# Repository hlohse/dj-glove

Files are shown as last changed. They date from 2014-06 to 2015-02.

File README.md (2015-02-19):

### Compilation

#### Windows

Make sure the following software is installed:

    Visual Studio Express 2013
    Arduino IDE

To make use of virtual MIDI ports, use the following 3rd party software:

    Go to http://www.tobias-erichsen.de/
    Download and install loopMIDI
    Download the virtualMIDI SDK
    Copy the following virtualMIDI SDK C files to the ThirdParty directory:
        teVirtualMidi.h
        teVirtualMidi32.lib

#### Linux (Ubuntu 14.04)

Make sure the following packages are installed:

    g++ (>= 4.8)
    arduino
    libasound2-dev
    libbluetooth-dev

#### All Platforms

Pair your PC with the Arduino's Bluetooth module using the PIN 1234.

Adjust default Bluetooth address to your module's in PC/BluetoothDevice.cpp, BluetoothDevice::Arduino.

### About

Advanced project of Robotics Lab ST14, University of Heidelberg, Germany.

Authors: Jan-Lukas Tirpitz, Henning Lohse

Supervisors: Karsten Krispin, Thomas Kloepfer

[Demo Video](https://www.youtube.com/watch?v=biKKQlQEOuE)

[Project website (German)](http://joanna.iwr.uni-heidelberg.de/projects/2014SS_DJHANDSCHUH/hardware.html)

[Robotics Lab website](http://joanna.iwr.uni-heidelberg.de/rlab/en/about)

### Copyright

Copyright (c) 2014 Jan-Lukas Tirpitz, Henning Lohse

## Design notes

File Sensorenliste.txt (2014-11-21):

MOUSER:

Flex-Sensor: 5,60€
http://de.mouser.com/ProductDetail/Spectra-Symbol/FS-L-0055-253-ST/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

oder doch der lange?:

3x Beschleunigungssensor (3-Axis): 1,34€
http://de.mouser.com/ProductDetail/Freescale-Semiconductor/MMA8451QR1/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

Entfernungsmesser(1 - 200mm): 2,42€
http://de.mouser.com/ProductDetail/Vishay-Semiconductors/VCNL3020-GS08/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

6x empfindliche Minidruckknöpfe (zwischen die Finger): 0,80€
http://de.mouser.com/ProductDetail/Panasonic/EVP-AWBA2A/?qs=sGAEpiMZZMsgGjVA3toVBGTSKfeK9LPKxL05x3Q68mA%3d

4x Potentiometer 0,60€:
http://de.mouser.com/ProductDetail/Bourns/PTV09A-4015F-B503/?qs=sGAEpiMZZMtC25l1F4XBU4LIzrlRxKBZi5l7wwo1KCE%3d

7-segment-anzeige 8 (2 digits):
http://de.mouser.com/ProductDetail/Kingbright/ACDA02-41SGWA-F01/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

7-segment-treiber + SR:
http://de.mouser.com/ProductDetail/STMicroelectronics/STP16CP05MTR/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

4x Drehknöpfe: 0,634€
http://de.mouser.com/ProductDetail/Eagle-Plastic-Devices/450-4760/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
eventuell auch andre mit eingebauter Druckknopffunktion oder Stufendrehschalter für Pgrogramm-/Kanal-Wahl

10x Druckknöpfe:
http://de.mouser.com/ProductDetail/Schurter/13019314/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

2x Spannungsregler:
http://de.mouser.com/ProductDetail/Texas-Instruments/UA78M33CDCYR/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

Schmitt-Trigger:
http://de.mouser.com/ProductDetail/STMicroelectronics/M74HC14YRM13TR/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

Kondensator: Elektrolyt 22uF
http://de.mouser.com/ProductDetail/Nichicon/UWX0J220MCL2GB/?qs=sGAEpiMZZMtZ1n0r9vR22RxmuzErLMSV6cxZgqZwSVw%3d

Kondensator: Elektrolyt 10uF
http://www.mouser.de/ProductDetail/Cornell-Dubilier/AVE106M16A12T-F/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

FARNELL:

Gyroskop: 8,88€
http://de.farnell.com/stmicroelectronics/l3g4200d/gyro-mems-3achsen-16llga-16lga/dp/1872924

1,0V-Spannungswandler: 1,10€
http://de.farnell.com/stmicroelectronics/ld39015m10r/v-reg-1-5-5-5v-0-15a-1v-5sot23/dp/2311330

KeKo 10nF: 
http://de.farnell.com/avx/08051c103jat2a/keramikkondensator-0-01uf-100v/dp/2332713

Keko 470nF:
http://de.farnell.com/jsp/search/productdetail.jsp?sku=1867963

CONRAD:
2x SChiebeschalter (on/off - bypass)
LiPo (3,7V, 2000mAh mindestens): 10,81€

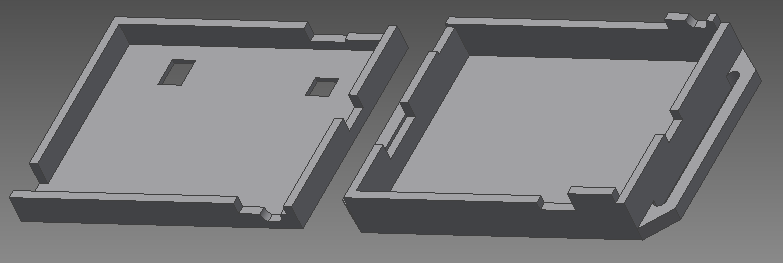
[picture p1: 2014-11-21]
Akkubox/Akkubox.png

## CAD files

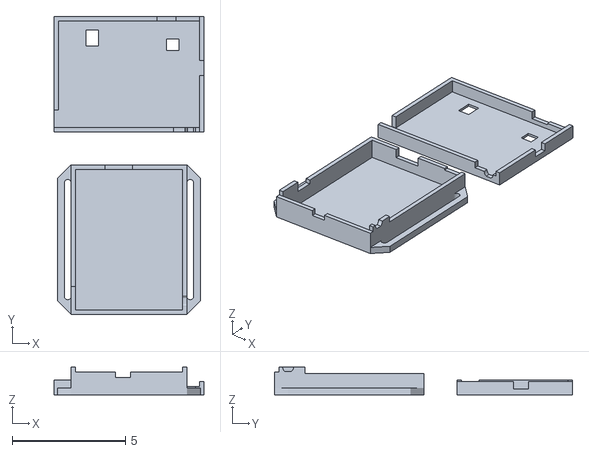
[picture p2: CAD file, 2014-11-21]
Akkubox/Akkubox.stl
6.60 x 13.1 x 1.23

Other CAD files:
Akkubox/Akkubox.ipt
Akkubox/OldVersions/Akkubox.0004.ipt

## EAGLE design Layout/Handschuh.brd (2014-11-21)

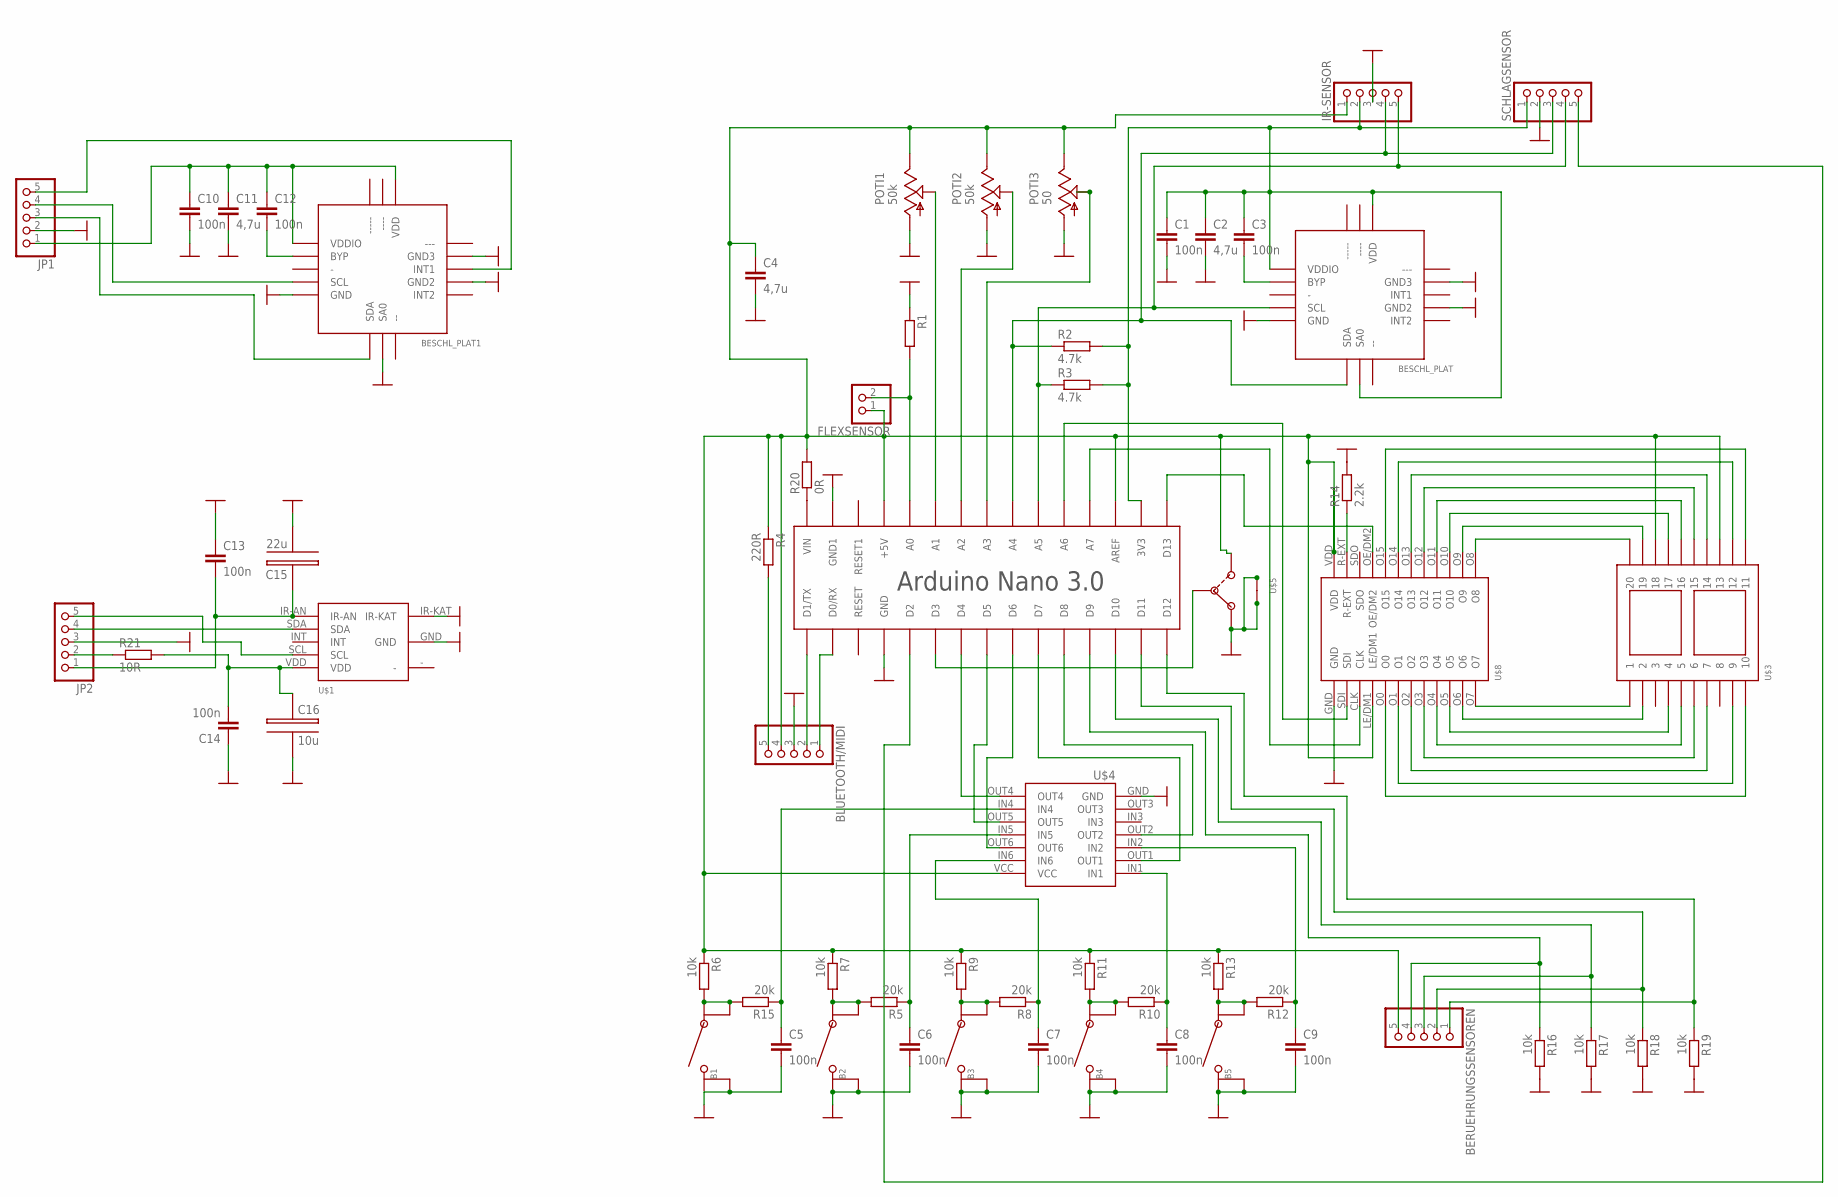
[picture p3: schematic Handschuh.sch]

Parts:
B1, B2, B3, B4, B5: BUTTON
BERUEHRUNGSSENSOREN: PINHD-1X5/90; 1X05/90
BESCHL_PLAT, BESCHL_PLAT1: BESCHLEUNIGSUNGSSENSOR; BESCHLEUNIGUNGSSENSOR
BLUETOOTH/MIDI: PINHD-1X5/90; 1X05/90
C1, C3, C5, C6, C7, C8, C9, C10, C12, C13, C14: 100n; C0805
C2, C4, C11: 4,7u; C0805
C15: 22u; 22U-KONDENSATOR
C16: 10u; 22U-KONDENSATOR
FLEXSENSOR: PINHD-1X2/90; 1X02/90
IR-SENSOR: PINHD-1X5/90; 1X05/90
JP1, JP2: PINHD-1X5/90; 1X05/90
POTI1, POTI2: 50k; POTI
POTI3: 50; POTI
R1: R-EU_M0805; M0805
R2, R3: 4.7k; M0805
R4: 220R; M0805
R5, R8, R10, R12, R15: 20k; M0805
R6, R7, R9, R11, R13, R16, R17, R18, R19: 10k; M0805
R14: 2.2k; M0805
R20: 0R; M0805
R21: 10R; M0805
SCHLAGSENSOR: PINHD-1X5/90; 1X05/90
U$1: IR-SENSOR
U$2: ARDUINONANO; PDIP-32
U$3: 7-SEGMENT
U$4: SCHMITT-TRIGGER
U$5: SCHALTER
U$8: 7-SEGMENT-TREIBER

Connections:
3,3V: BESCHL_PLAT.SA0, BESCHL_PLAT.VDD, BESCHL_PLAT.VDDIO, C1.1, C2.1, C3.1, IR-SENSOR.2, R2.2, R3.2, SCHLAGSENSOR.1, U$2.3V3
3,3V1: BESCHL_PLAT1.VDD, BESCHL_PLAT1.VDDIO, C10.1, C11.1, C12.1, JP1.1
5V: BERUEHRUNGSSENSOREN.5, BLUETOOTH/MIDI.4, C4.1, FLEXSENSOR.1, IR-SENSOR.1, POTI1.VCC, POTI2.VCC, POTI3.VCC, R4.1, R6.1, R7.1, R9.1, R11.1, R13.1, R20.2, U$2.+5V, U$2.AREF, U$3.13, U$3.18, U$4.VCC, U$5.3, U$8.LE/DM1, U$8.VDD
GND: B1.2, B2.2, B3.2, B4.2, B5.2, BESCHL_PLAT.GND, BESCHL_PLAT.GND2, BESCHL_PLAT.GND3, BESCHL_PLAT1.GND, BESCHL_PLAT1.GND2, BESCHL_PLAT1.GND3, BESCHL_PLAT1.SA0, BLUETOOTH/MIDI.3, C1.2, C2.2, C4.2, C5.2, C6.2, C7.2, C8.2, C9.2, C10.2, C11.2, C13.1, C14.1, C15.-, C16.-, IR-SENSOR.3, JP1.2, JP2.3, POTI1.GND, POTI2.GND, POTI3.GND, R1.1, R14.2, R16.2, R17.2, R18.2, R19.2, SCHLAGSENSOR.2, U$1.GND, U$1.IR-KAT, U$2.GND, U$2.GND1, U$4.GND, U$5.1, U$5.4, U$5.5, U$8.GND
unnamed: R20.1, U$2.VIN
unnamed: BESCHL_PLAT1.BYP, C12.2
unnamed: B1.3, B1.4, R6.2, R15.2
unnamed: FLEXSENSOR.2, R1.2, U$2.A0
unnamed: BESCHL_PLAT.BYP, C3.2
unnamed: SCHLAGSENSOR.5, U$2.D2
unnamed: POTI1.VALUE, U$2.A1
unnamed: POTI2.VALUE, U$2.A2
unnamed: POTI3.VALUE, U$2.A3
unnamed: BESCHL_PLAT1.SCL, JP1.4
unnamed: BLUETOOTH/MIDI.2, U$2.D1/TX
unnamed: BLUETOOTH/MIDI.1, U$2.D0/RX
unnamed: BLUETOOTH/MIDI.5, R4.2
unnamed: BESCHL_PLAT1.SDA, JP1.3
unnamed: C6.1, R5.1, U$4.IN5
unnamed: B2.3, B2.4, R5.2, R7.2
unnamed: C7.1, R8.1, U$4.IN6
unnamed: B3.3, B3.4, R8.2, R9.2
unnamed: C8.1, R10.1, U$4.IN1
unnamed: B4.3, B4.4, R10.2, R11.2
unnamed: C9.1, R12.1, U$4.IN2
unnamed: B5.3, B5.4, R12.2, R13.2
unnamed: U$2.D4, U$4.OUT4
unnamed: U$2.D5, U$4.OUT5
unnamed: U$2.D6, U$4.OUT6
unnamed: U$2.D7, U$4.OUT1
unnamed: U$2.D8, U$4.OUT2
unnamed: U$2.A6, U$8.SDI
unnamed: C5.1, R15.1, U$4.IN4
unnamed: U$2.A7, U$8.CLK
unnamed: U$3.9, U$8.O1
unnamed: U$3.1, U$8.O7
unnamed: U$3.2, U$8.O6
unnamed: U$3.4, U$8.O5
unnamed: U$3.5, U$8.O4
unnamed: U$3.6, U$8.O3
unnamed: U$3.7, U$8.O2
unnamed: U$3.10, U$8.O0
unnamed: U$3.20, U$8.O8
unnamed: U$3.19, U$8.O9
unnamed: U$3.17, U$8.O10
unnamed: U$3.16, U$8.O11
unnamed: U$3.15, U$8.O12
unnamed: U$3.14, U$8.O13
unnamed: U$3.12, U$8.O14
unnamed: U$3.11, U$8.O15
unnamed: BERUEHRUNGSSENSOREN.4, R16.1, U$2.D9
unnamed: R14.1, U$8.R-EXT
unnamed: U$2.D13, U$8.OE/DM2
unnamed: BESCHL_PLAT1.INT1, JP1.5
unnamed: BERUEHRUNGSSENSOREN.3, R17.1, U$2.D10
unnamed: BERUEHRUNGSSENSOREN.2, R18.1, U$2.D11
unnamed: BERUEHRUNGSSENSOREN.1, R19.1, U$2.D12
unnamed: U$2.D3, U$5.2
unnamed: BESCHL_PLAT.SCL, IR-SENSOR.5, R3.1, SCHLAGSENSOR.4, U$2.A5
unnamed: C13.2, C15.+, JP2.1, U$1.IR-AN
unnamed: C14.2, C16.+, R21.2, U$1.VDD
unnamed: BESCHL_PLAT.SDA, IR-SENSOR.4, R2.1, SCHLAGSENSOR.3, U$2.A4
unnamed: JP2.2, R21.1
unnamed: JP2.4, U$1.SDA
unnamed: JP2.5, U$1.SCL

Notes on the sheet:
Arduino Nano 3.0

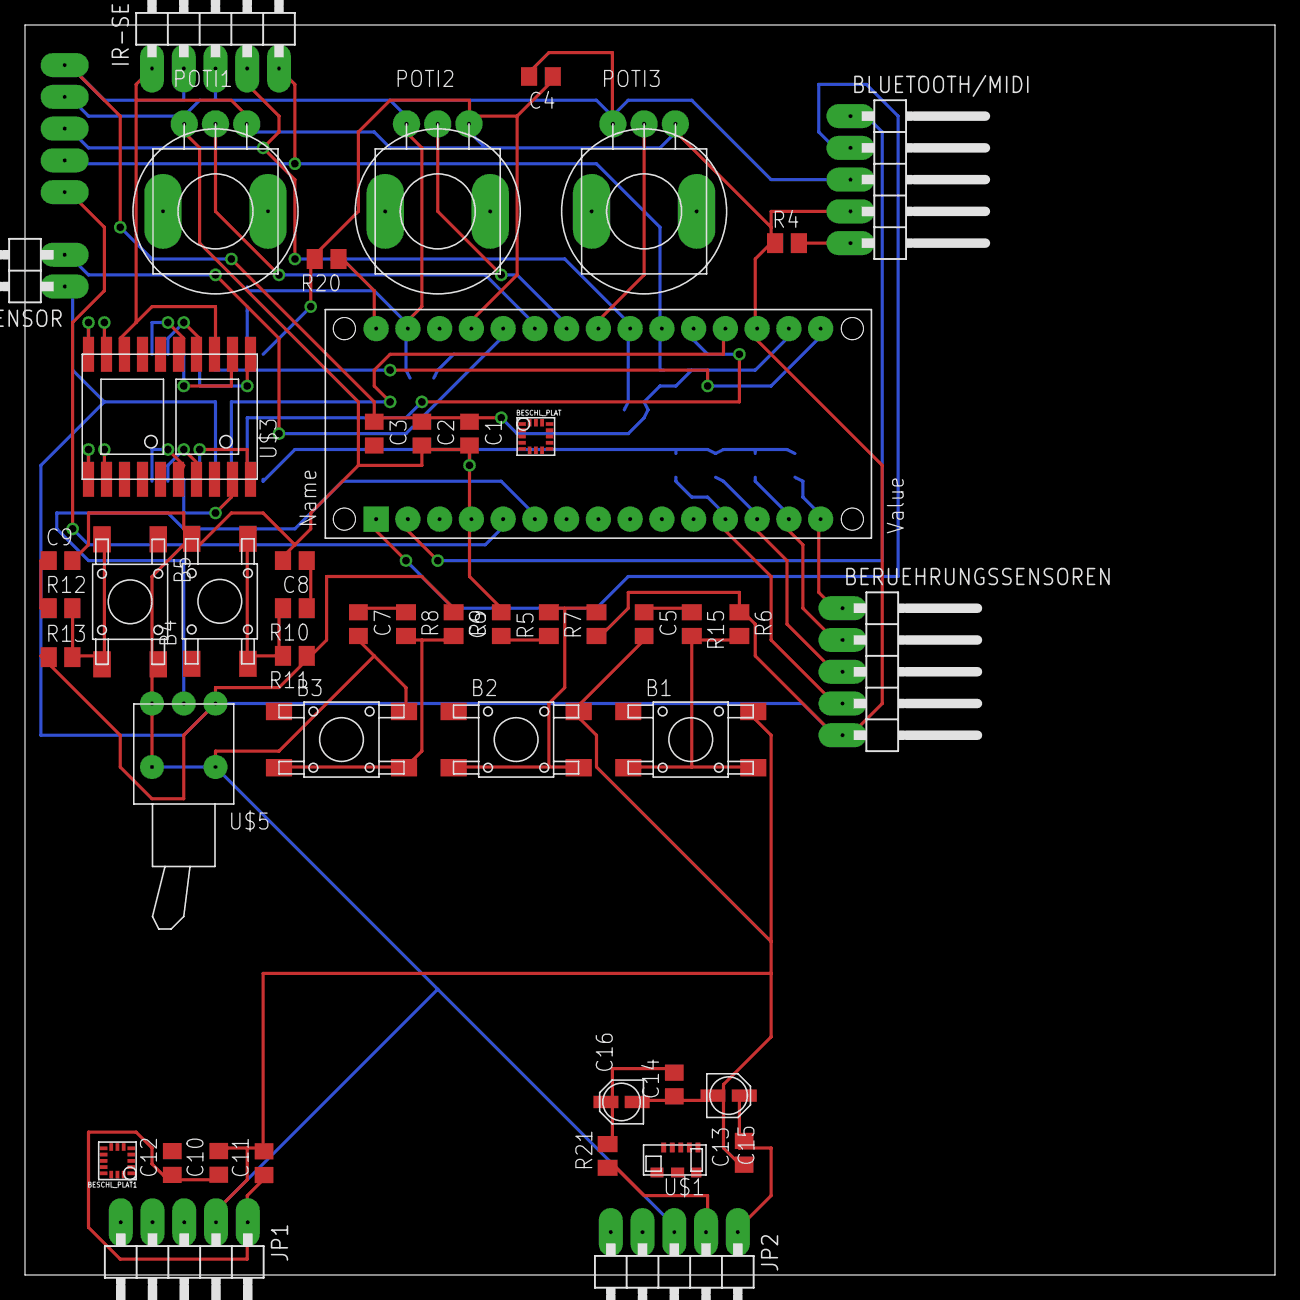
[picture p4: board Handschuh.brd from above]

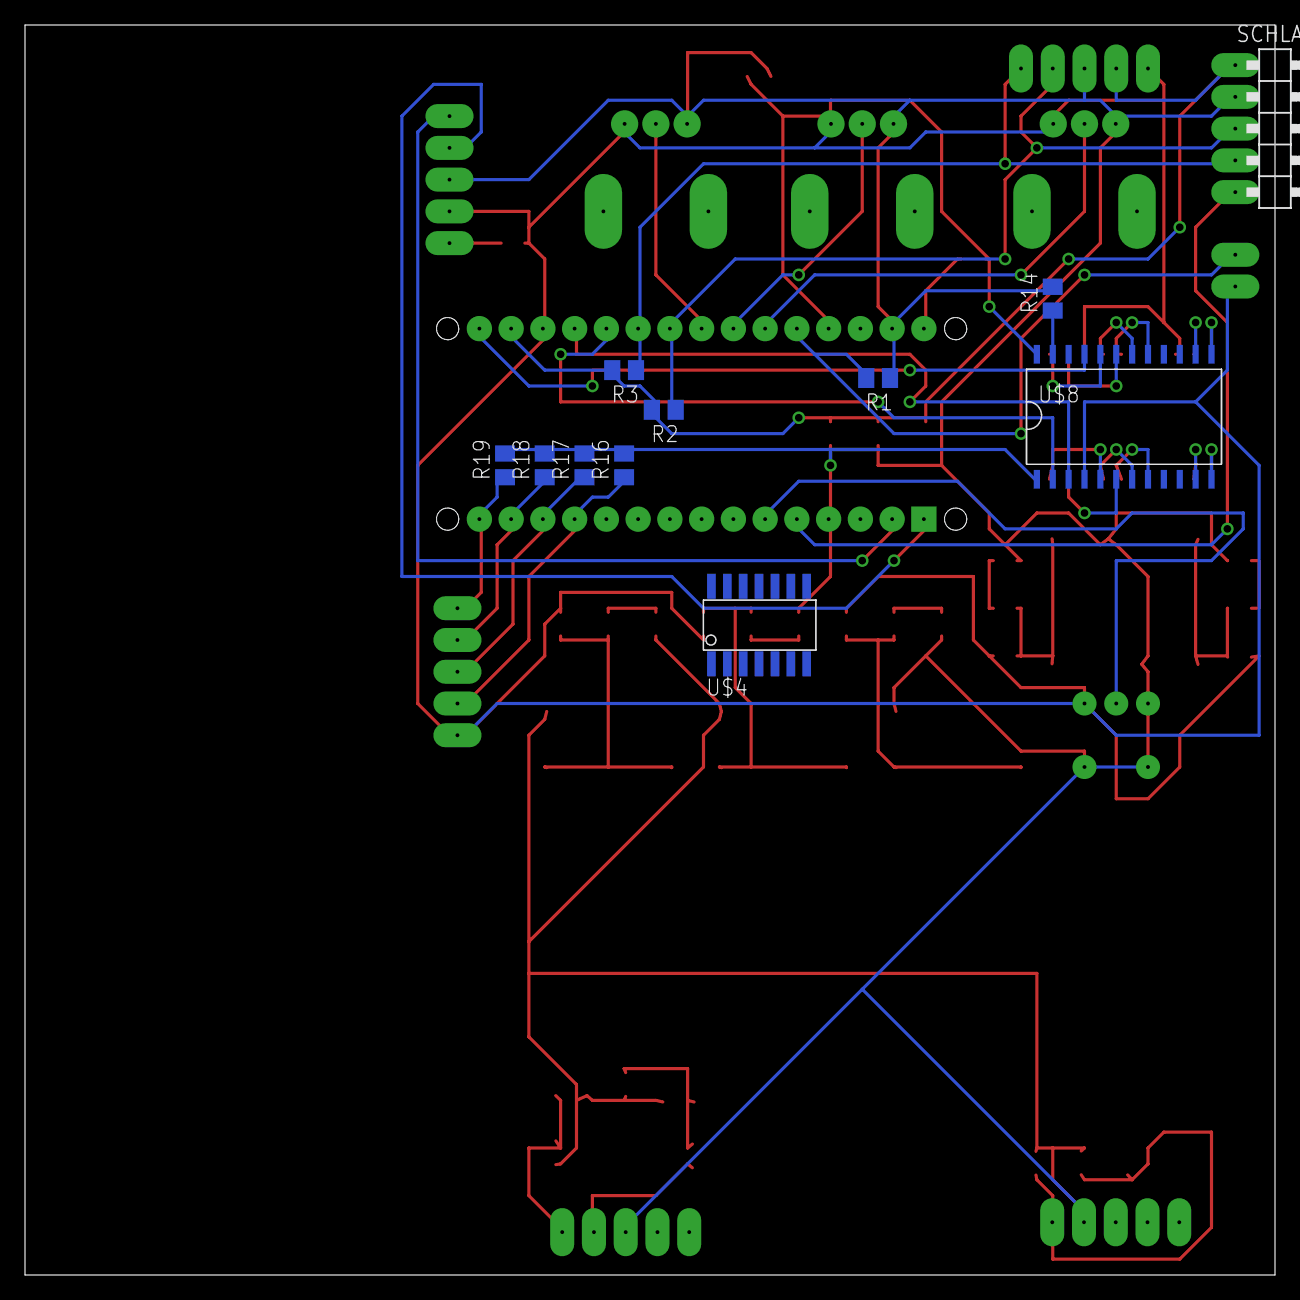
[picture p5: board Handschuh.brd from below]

Board: 2 copper layers, 100.0 x 100.0 mm, 60 parts (11 on the bottom side), 65 nets.

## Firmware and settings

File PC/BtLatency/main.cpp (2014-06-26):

#include "BtLatency.h"
#include "Platform.h"
#include "Bluetooth.h"
#include "BluetoothDevice.h"
#include <string>
#include <vector>
#include <utility>
#include <algorithm>
#include <iostream>
#include <iomanip>
#include <unistd.h>
#include <float.h>
#include <cmath>
#include <sys/time.h>
#include <sys/resource.h>
using namespace std;

typedef pair<struct timeval, struct timeval> time_tuple;
static const int timeout_s = 5;

typedef struct {
    double min;
    double max;
    double mean;
    double median;
    double stddev;
    double var;
} Result;

ISerial* GetSerial()
{
    BluetoothDevice arduino("Arduino",
                            Platform::bluetooth_mac,
                            Platform::bluetooth_channel);
    Bluetooth* bluetooth = new Bluetooth(arduino, string(BtLatency::message).length());
    
    bluetooth->Connect(timeout_s);
    
    return bluetooth;
}

void SyncStart(ISerial* serial)
{
    string start_signal(&BtLatency::start_signal,
                        sizeof(BtLatency::start_signal));
    
    serial->Write(start_signal);
}

void DetermineTimes(ISerial* serial, vector<time_tuple>& times)
{
    struct timeval start, stop;
    string expected_message(BtLatency::message);
    string message;

    times.reserve(BtLatency::num_messages);
    SyncStart(serial);

    for (unsigned int i = 0; i < BtLatency::num_messages; ++i) {
        gettimeofday(&start, NULL);
        message = serial->ReadNextAvailable(expected_message.length());
        gettimeofday(&stop, NULL);

        if (!serial->IsReady()) {
            cout << "Serial error: " << serial->GetLastError() << endl;
            break;
        }

        if (message.compare(expected_message) != 0) {
            cout << "ERROR: Received \"" << message
                 << "\", expected \"" << expected_message << "\"" << endl;
            break;
        }

        times.push_back(time_tuple(start, stop));
    }
}

void DetermineTimesMs(const vector<time_tuple>& times, vector<double>& times_ms)
{
    vector<time_tuple>::const_iterator it;

    for (it = times.begin(); it != times.end(); ++it) {
        double start_time_us = it->first.tv_sec  * 1e6 + it->first.tv_usec;
        double stop_time_us  = it->second.tv_sec * 1e6 + it->second.tv_usec;

        double total_time_ms = (stop_time_us - start_time_us) / 1e3;
       
        times_ms.push_back(total_time_ms);
    }
}

Result GetResult(vector<double>& times_ms)
{
    vector<double> times_ms_sorted(times_ms);
    vector<double>::const_iterator it;
    Result result;
    
    sort(times_ms_sorted.begin(), times_ms_sorted.end());

    result.min    = DBL_MAX;
    result.max    = DBL_MIN;
    result.mean   = 0;
    result.median = times_ms[times_ms_sorted.size() / 2];
    result.var    = 0;

    for (it = times_ms.begin(); it != times_ms.end(); ++it) {
        const double time = *it;

        if (time < result.min) {
            result.min = time;
        }
        if (time > result.max) {
            result.max = time;
        }

        result.mean += time;
    }

    result.mean /= times_ms.size();
    
    for (it = times_ms.begin(); it != times_ms.end(); ++it) {
        const double time = *it;
        result.var += (time - result.mean) * (time - result.mean);
    }

    result.var   /= times_ms.size();
    result.stddev = sqrt(result.var);

    return result;
}

void ShowResult(const Result& result, const vector<double>& times_ms)
{
    vector<double>::const_iterator it;

    cout << setprecision(2) << fixed;
    
    for (it = times_ms.begin(); it != times_ms.end(); ++it) {
        cout << it - times_ms.begin() << " " << *it << " ms" << endl;
    }

    cout << "min\tmax\tmean\tmedian\tstddev\tvar\t[ms]" << endl;
    cout << result.min    << "\t"
         << result.max    << "\t"
         << result.mean   << "\t"
         << result.median << "\t"
         << result.stddev << "\t"
         << result.var    << endl;
}

int main()
{
    ISerial* serial = GetSerial();
    vector<time_tuple> times;
    vector<double> times_ms;

    if (!serial->IsReady()) {
        cout << "Serial error: " << serial->GetLastError() << endl;
        return -1;
    }

    DetermineTimes(serial, times);

    if (times.size() == BtLatency::num_messages) {
        Result result;

        DetermineTimesMs(times, times_ms);
        result = GetResult(times_ms);
        ShowResult(result, times_ms);
    }

    delete serial;
    return 0;
}

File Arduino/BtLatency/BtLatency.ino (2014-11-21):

#include <Arduino.h>
#include <SoftwareSerial.h>

// Comment out to use hardware Serial pins RX0, TX1
//#define USE_SOFTWARE_SERIAL 1

#ifdef USE_SOFTWARE_SERIAL
SoftwareSerial bluetooth(2, 3);
#define SERIAL bluetooth
#else
#define SERIAL Serial
#endif

// NOTE: USE THIS VALUES IN PC PROJECT, TOO!
const int   iterations = 1200;
const char  message    = '!';

void setup()  
{
#ifdef USE_SOFTWARE_SERIAL
  bluetooth.begin(9600);
#else
  Serial.begin(115200);
#endif
}

void loop()
{
  for (int i = 0; i < iterations; ++i) {
    while (!Serial.available());
    if (Serial.read() == message) {
      Serial.write(message);
    }
  }
}

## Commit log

2014-06-17 * Added build, lib, inc and src directories * build, inc and src have arduino and midiserver subdirs
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2014-06-17 Revert "Added Arduino Blink basic example to sources"
    This reverts commit 96d4ca2e5d37cda4671e8fc9c7b83ebec26619f9.
2014-06-17 * Added directories Arduino, PC and ThirdParty * Arduino and PC contain build, inc and src directories for development on both architectures * ThirdParty is on .gitignore
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2014-06-19 Revert "Started Makefile including Arduino processing,"
    This reverts commit 1aae7c41ad6667d9326a8a3ee617025c9303064b.
2014-06-19 Arduino directory now has just common subdirectory. Sketches will need their own directory
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2014-06-19 Added Platform.h to Arduino/common to provide board configuration, e.g. pin usage, baud rates etc.
2014-06-19 Added Bluetooth to Arduino common libs. It provides a SoftwareSerial and setup function for Bluetooth communication
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2014-06-21 * Added top-level Makefile * Executes Makefile for each project in Arduino directory * Can be configured via Config.mk
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2014-06-22 BluetoothDevice uses channel, constructs socket address correctly
2014-06-22 Implemented Bluetooth::Connect to connect to given device via Bluetooth RFCOMM socket
2014-06-22 * Adopted ISerial changes to Bluetooth * As ioctl returns size of next message and not all socket data, WaitUntilAvailable uses read to buffer into buffer_ internally until the requested length is bu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
2014-06-22 * Renamed BtPingPong to BtLatency * Arduino sends 1000x PING * PC currently just displays them
2014-06-22 * Fixed missing ISerial virtual destructor * Directory common in root directory to share infos between Arduino and PC projects * Move Platform.h to common * Created BtLatency.h in common to configure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
    [BtLatency.ino, Platform.h, main.cpp]
2014-06-22 BtLatency, Arduino and PC send each other 1000x PING alternating. Measured is roundtrip time, displayed in detail (min/max/mean/median/stddev/var)
2014-06-26 * BtLatency doesn't sync back with PC * Fixed sorting bug * 65535x PING is measured * Results included
    [BtLatency.ino, main.cpp]
2014-07-01 Heavily changed project structure: * Arduino projects are no longer compiled via Makefile * Use IDE to compile Arduino project from their ino file * Copy/link libraries into Arduino installation fold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
    [BtLatency.ino]
2014-07-03 * BluetoothDevice uses channel as port on Windows * Bluetooth uses send/recv instead of _write/_read for Windows sockets
2014-07-03 Implemented Arduino library Midi providing information, enums and functions for MIDI signal processing
2014-07-05 Fixed Midi pitch bend bit fiddles
2014-07-05 Implemented Entchen Arduino project. After receiving start signal '!', it sends MIDI signals playing Alle meine Entchen via Bluetooth :)
2014-07-05 Implemented MidiPlayer Arduino library. Provides a set of channels that can be played via Bluetooth. Sends number of signal bytes before 2-3 MIDI signal bytes
2014-07-10 BtConfig Arduino project to change Bluetooth module's configurations
2014-07-10 Arduino BtLatency can switch between software and hardware serial via define falg
2014-08-05 Added stub for DjGloveSignal to differentiate between punch and other sensor signals sent by the Arduino to transform to MIDI signals
2014-08-05 Adopted Arduino MidiChannel code to PC MidiSignal to allow easy control of raw MIDI signals
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2014-08-05 Fixed BluetoothDevice::Arduino
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2014-08-06 Implemented SignalsSensor's conversion of sent Arduino bytes to button and sensor values
2014-08-06 SensorsSignals produces example MIDI signal using Poti 0
2014-08-06 Fixed SensorsSignal::SetChannelFrom
2014-08-06 Implemented DjGlove struct to handle sensor data etc.
2014-08-06 DataProtocol implements Arduino-sent byte transformations into DjGlove struct data
2014-08-06 DjGlove processes data with DataProtocl to update sensor information. Stub for MIDI signal generation included
2014-09-06 DataProtocol decrements raw data by 1 before applying. This is because the Arduino increments data to be sent via Bluetooth by 1, as zero/null bytes can not be send.
2014-09-14 Bluetooth creates sockets on Connect, not in constructor. Reason is that without SetUp called, socket creation for an e.g. local variable might fail
2014-09-15 * Implemented initial DjGlove Arduino application stub * Implemented Led class to control both LEDs via shift registers
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2014-09-15 Implemented PushButton class with fixed number of calls to isPushed to debounce read digital value
    [DjGlove.ino]
2014-09-15 Stub for Flex class
    [DjGlove.ino]
2014-09-15 * Renamed Push to Button * DjGlove contains additional touch buttons * Data transforms all buttons, potis, flex, channel, program; distance, orientation and flip button still missing
2014-09-15 Added flip Button to DjGlove and Data
2014-09-15 Test code to print data bytes via Serial
2014-09-15 * Entered more pins * Fixed binary output
    [DjGlove.ino]
2014-09-15 Fixed LED display
2014-09-15 Started UltraSound implementation, needs read fix
    [DjGlove.ino]
2014-09-24 UltraSound reinitializes after every (potentially failed) read and wait at least 70ms correctly
    [DjGlove.ino]
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2014-09-24 Reverted to test code
    [DjGlove.ino]
2014-09-25 * Removed Bluetooth Arduino library * Adjusted existing Arduino projects accordingly
2014-09-25 DjGloveServer prints DjGlove data state after each receiving
2014-09-25 Fixed DjGlove constructor initializations. Wire.begin() cannot be called during that, so some components need explicit initialization methods.
    [DjGlove.ino]
2014-09-25 Fixed Gyro axis register addresses
2014-09-25 Arduino Data increments byte to send by 1
2014-09-26 Button provides assignOnPress/-Release methods to specify handler routines for pressed/released buttons
2014-09-26 * DjGlove is singleton; access instance pointer via DjGlove::instance() * Assigned push buttons 0, 1 to increase channel, program
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2014-09-26 Revert "Data uses DjGlove singleton instance"
    This reverts commit b71d2b2479e4ebcd8bb72c9f36af3fffdcdc0d8c.
    [DjGlove.ino]
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2014-09-26 Fixed display of program and channel via LED
    [DjGlove.ino]
2014-09-26 Displays P and C on LED on startup for 1.5s
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2014-09-26 LED displays from 1 to 0 (0 = 10)
2014-09-26 Fixed Data index after hit occurence
    [DjGlove.ino]
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2014-09-30 Implemented RingFifo as FIFO data structe overwriting oldest values in circular/ring fashion if insertion occurs while full
2014-09-30 Fixed RingFifo::insert to set m_is_full correctly
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2014-10-06 Nochmal Accelerationkorrektur und kleine Änderungen in Dateien vom 1.10
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2014-10-07 * Scaled Flex readout to 0..127 for closed hand to stretched hand * Faster Gyro readout using auto increment for axis registers
2014-10-07 * Only read Gyro's x and y axis * Protocol transfers x/y as 7 bit pairs (= 14 bit resolution per axis)
2014-10-07 Transfers Gyro signedness correctly
2014-10-07 Fixed Protocol bit shifts; fills 0 for <<, 1 for >>
    [DjGlove.ino]
2014-10-07 Fixed to hit detection, misplaced ifdef and sync
    [DjGlove.ino]
2014-10-07 * Sends abs of gyro values with signed bit * PC applies *=-1/*=1 to abs after receive * bool to check whether x/y is updating
2014-10-07 Implemented Orientation to handle x/y axis acceleration with updating value from low/high byte via integration
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2014-10-08 * Print MidiSignal as int values * Orientation uses performance counter for time on Windows * Integrated ControllerSwitch
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2014-10-08 Fixed Bluetooth::Write for single char * Exluded Orientation Windows code on Linux * Removed warmups from BtLatency, just drop first value * Latency measurement results
    [BtLatency.ino]
2014-10-08 ControllerPush-Klasse hinzugefügt. Sendet highValue beim Drücken und lowValue beim loslassen
2014-10-09 * Default MidiSignal constructors for key, controller, pitch bend * Introduced Controller class providing interface Changed, Signal * Removed ControllerPush * ControllerSwitch implements Controller, 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
2014-11-21 Added Layouts
    [Handschuh.brd, Handschuh.sch, HandschuhGyro.brd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]
2014-11-21 Added Akkubox 3D print files
    [Akkubox.0004.ipt, Akkubox.ipt, Akkubox.stl]
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
